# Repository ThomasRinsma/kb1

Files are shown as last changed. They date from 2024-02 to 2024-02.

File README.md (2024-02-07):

# `kb1`: a fully DIY mechanical keyboard

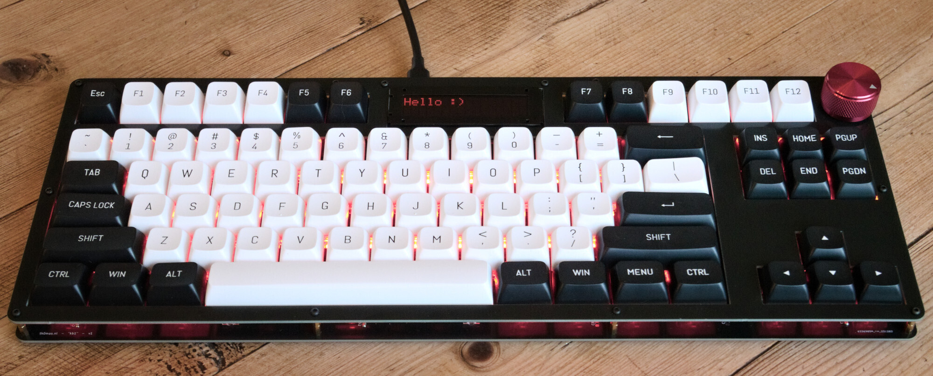
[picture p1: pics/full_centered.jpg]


Features:

- Mechanically built using two PCBs and a few screws and standoffs.
- Proper "tenkeyless" layout, compatible with Cherry MX-style switches (mine with Kailh box crystal jades)
- Per-key RGB backlight using reverse-mounted SK6812 neopixels
- Featuring an old-school 16x2 character display
- And of course a _knob_ (rotary encoder)
- Based on the Raspberry Pi Pico and [KMK](https://github.com/KMKfw/kmk_firmware)

## Why?

To challenge myself and practice PCB design!

Is it tons of fun to design and build your own keyboard from scratch? Hell yeah. Would I recommend this board for daily use? Not really :^)

## PCB

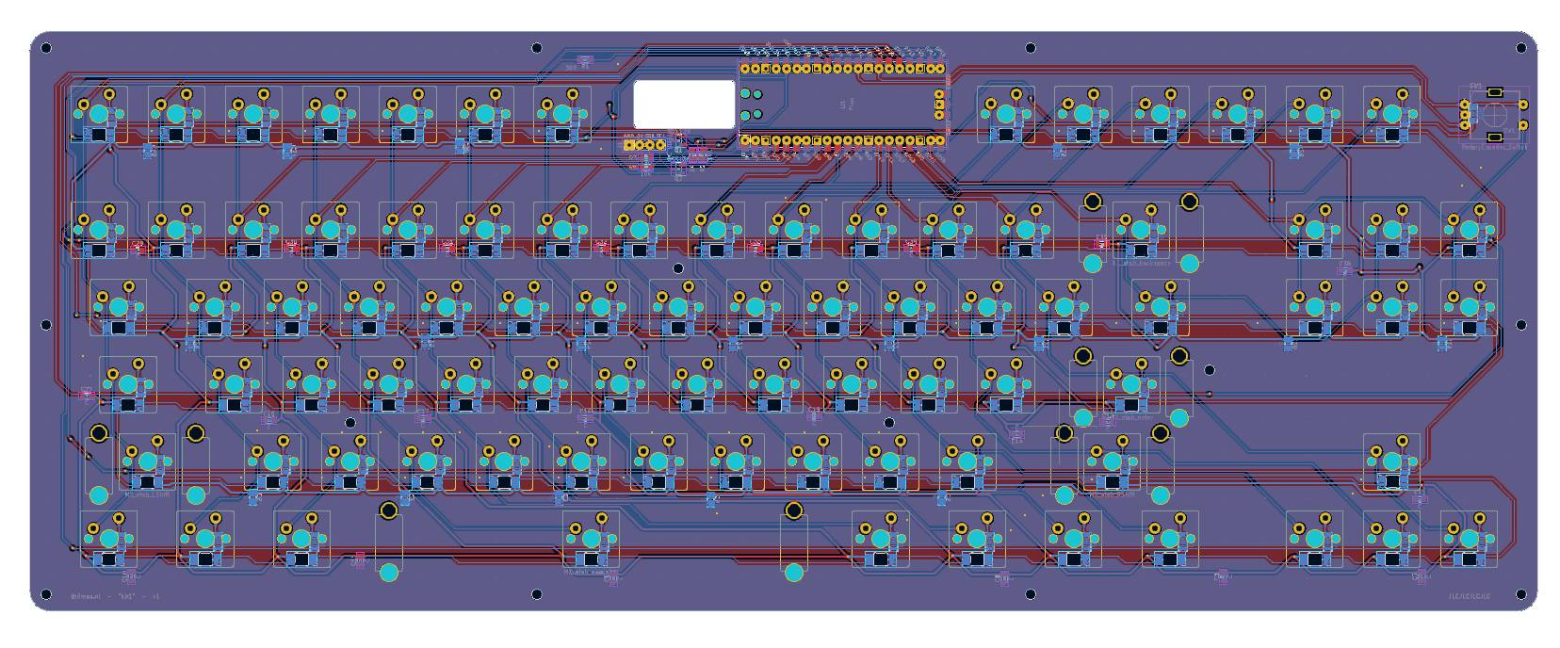
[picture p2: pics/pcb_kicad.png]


See `hardware/` for the KiCad files. There is a `gerbers/` folder with ZIP files ready to upload to a PCB fab.

## Firmware

Installing:
1. Grab Circuitpython, the Adafruit Circuitpython Neopixel library, and the KMK base files
2. Copy `firmware/*.py` to your Circuitpython drive

It's just a simple KMK setup with scaffolding code for the display and RGB. Actually doing something with the display is still TBD.

As a demo there is currently a bit of logic to map individual RGB leds to keys so it can light up a key when pressed. Twisting the knob changes the overall backlight color.

## Pics

| | |
|:---:|:---:|
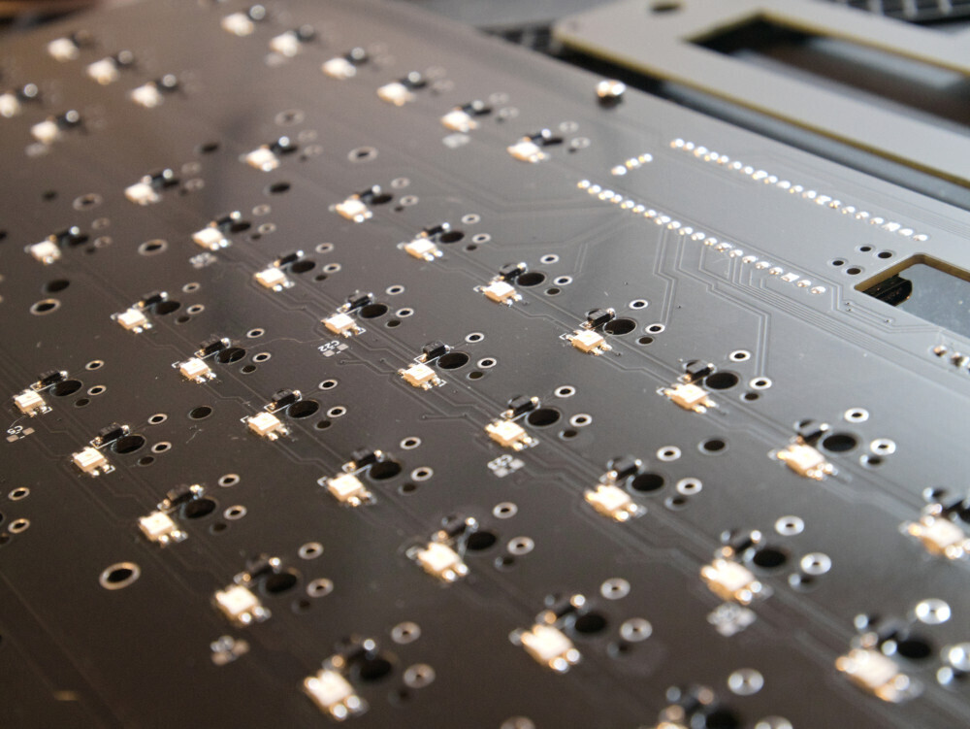
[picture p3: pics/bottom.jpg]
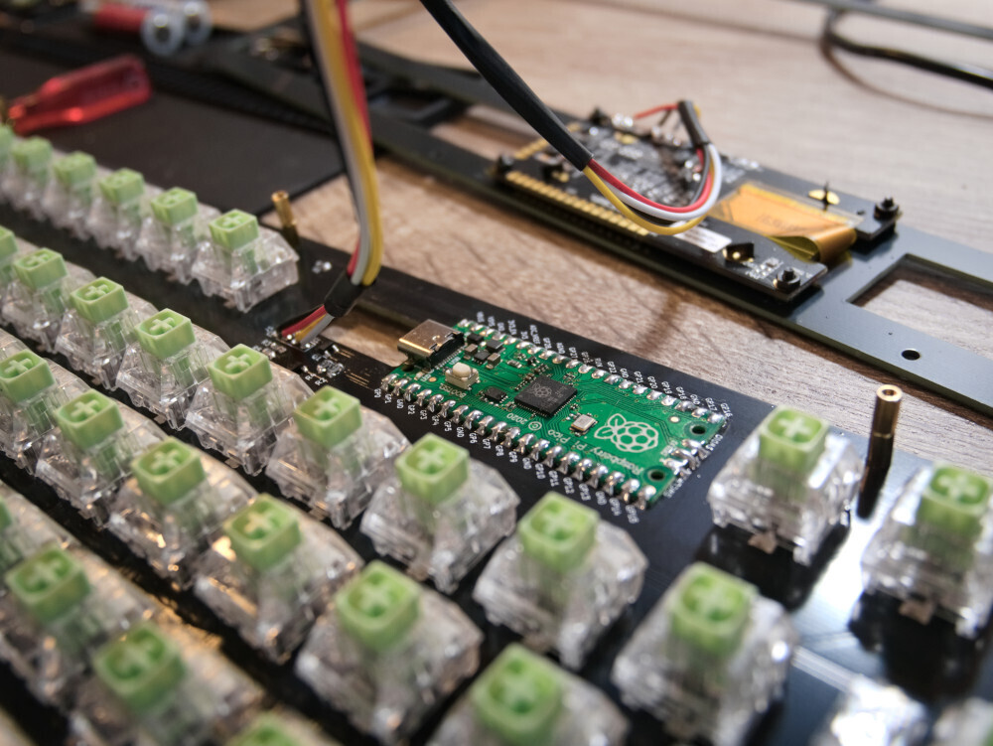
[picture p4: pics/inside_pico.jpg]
|||
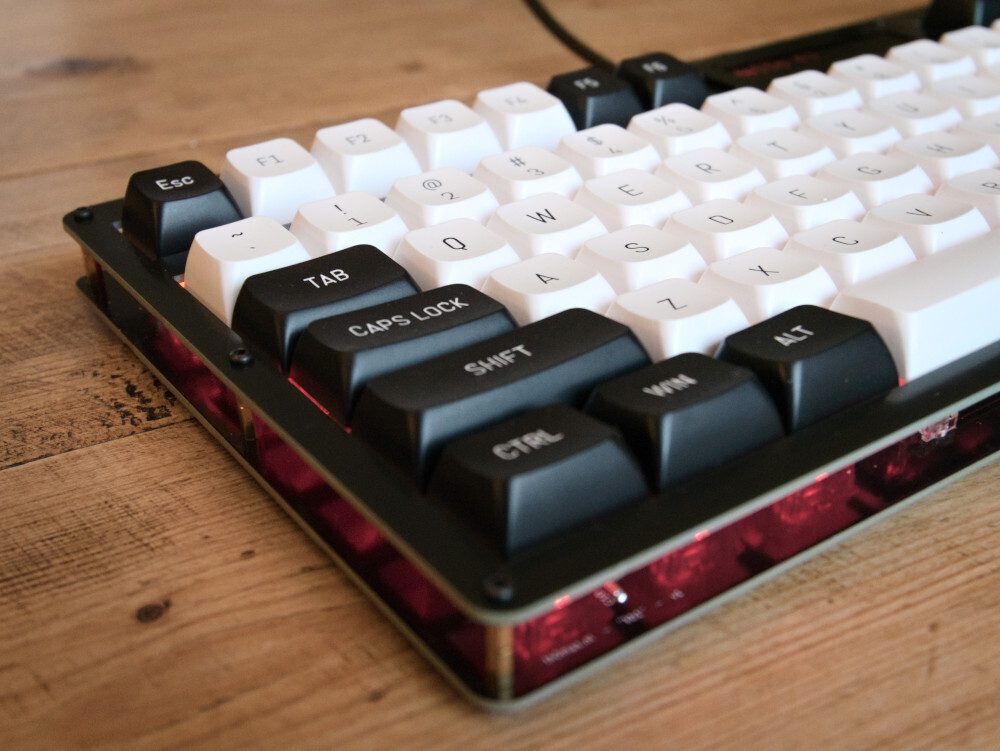
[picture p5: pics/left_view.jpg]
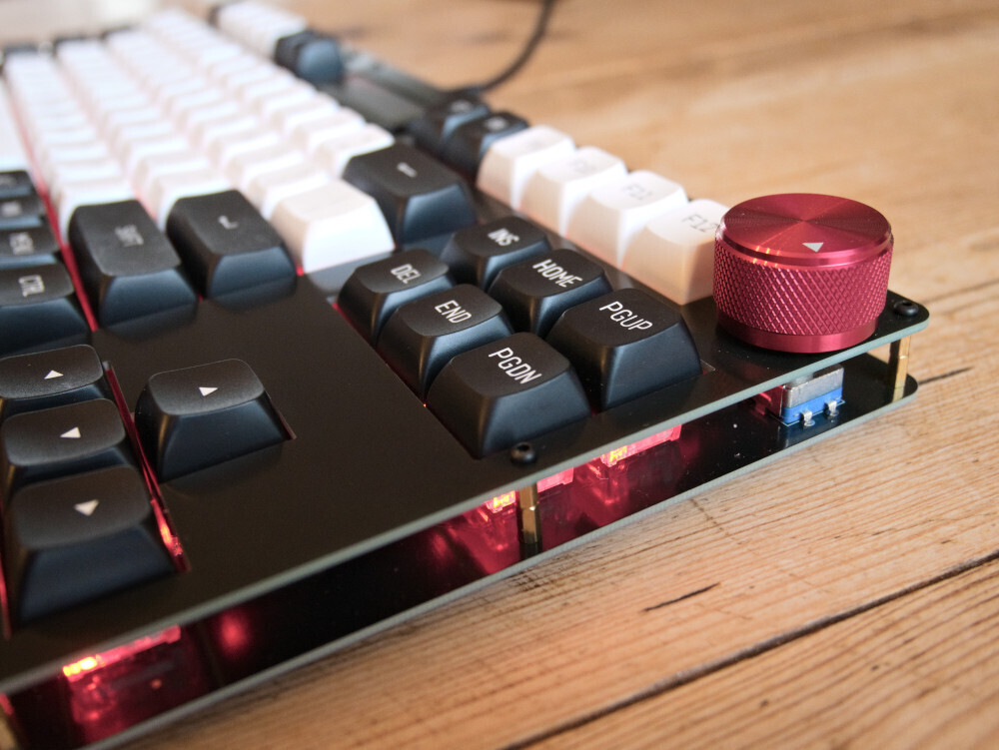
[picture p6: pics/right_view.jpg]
|||
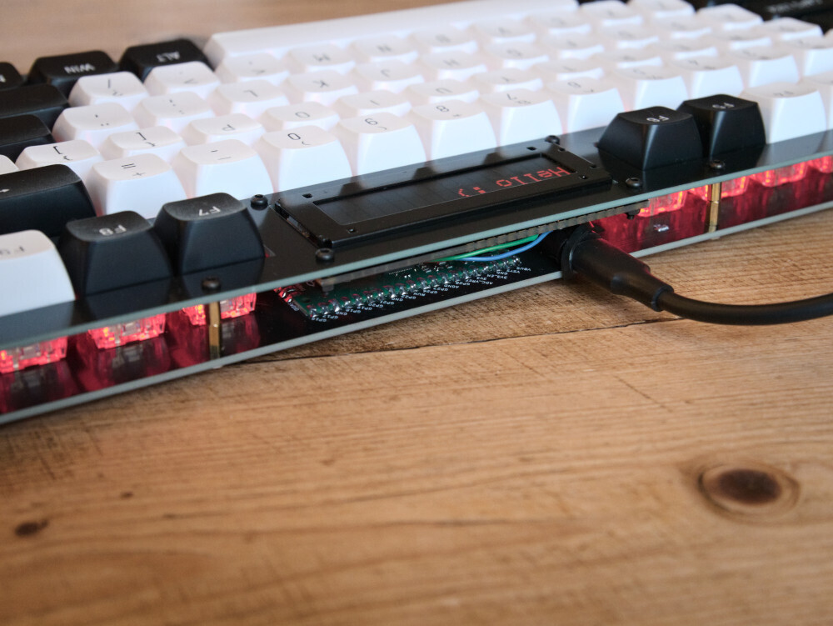
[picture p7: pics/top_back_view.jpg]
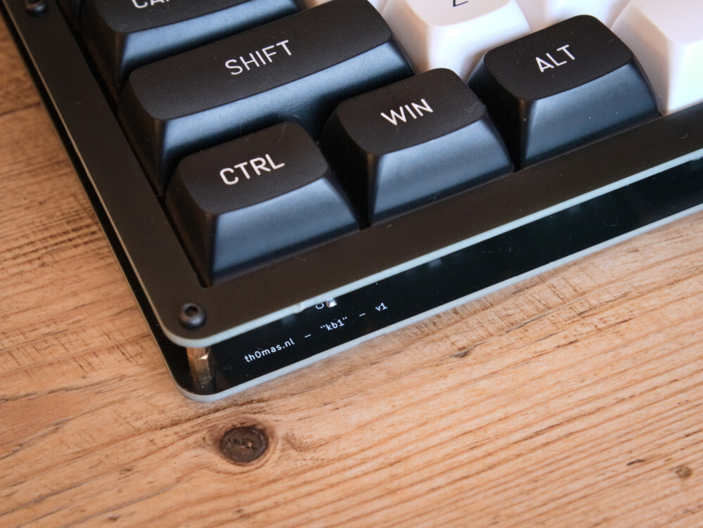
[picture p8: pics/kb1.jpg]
|||

## Errata / improvements for next version

Latest version: v1 (but the gerbers say v2, sorry..)

- Display pinout doesn't work well with a JST connector due to the orientation, requires manual soldering
- Pico orientation is awkward, I needed a USB type-C 90 degree adapter
- Several nuts nearly touch (covered) traces, doesn't appear to be a problem though
- The top plate could have some more copper for rigidity

## BoM

TODO

## Disclaimer 

This is my own hobby project and I'm a total PCB design newbie. Use the info and files provided here at your own risk.

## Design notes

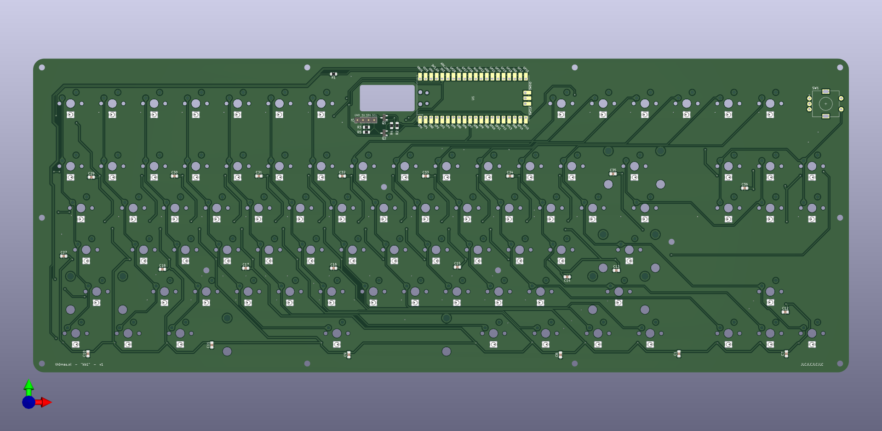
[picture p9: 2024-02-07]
pics/pcb_render.png

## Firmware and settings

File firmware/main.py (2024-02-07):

print("Starting")

import board
import neopixel
import time

from display import init, home, clear, writeData

init()
home()
writeData("Booting...")


from kmk.kmk_keyboard import KMKKeyboard
from kmk.keys import KC, make_key
from kmk.scanners import DiodeOrientation
from kmk.extensions.stringy_keymaps import StringyKeymaps
from kmk.modules.encoder import EncoderHandler


pixels = neopixel.NeoPixel(
    board.GP28,
    100,
    pixel_order=neopixel.GRB,
    brightness=1
)

COLORS = [
    (32, 0, 0),
    (32, 16, 0),
    (0, 32, 0),
    (0, 32, 32),
    (0, 0, 32),
    (16, 0, 32),
    (32, 32, 32),
    (0, 0, 0),
]

pixel_idle_color = 0

keyboard = KMKKeyboard()
keyboard.extensions.append(StringyKeymaps())

encoder_handler = EncoderHandler()
keyboard.modules.append(encoder_handler)

keyboard.col_pins = (board.GP26,board.GP27,board.GP2,board.GP3,board.GP4,board.GP5,board.GP6,board.GP7,board.GP8,board.GP9,board.GP10,board.GP11,board.GP12,board.GP13,board.GP14)
keyboard.row_pins = (board.GP15,board.GP20,board.GP19,board.GP18,board.GP17,board.GP16)
keyboard.diode_orientation = DiodeOrientation.COL2ROW
encoder_handler.pins = ((board.GP21, board.GP22, None),)  # Encoder click is handled via key matrix (top right)

def handle_encoder_click(key, kb, kc, coord):
    print(f"encoder click")

def handle_encoder_rotate(key, kb, kc, coord):
    global pixel_idle_color
    if key.direction == 1: # left
        pixel_idle_color = (pixel_idle_color - 1) % len(COLORS)
        pass
    elif key.direction == 2: # right
        pixel_idle_color = (pixel_idle_color + 1) % len(COLORS)
        pass

    pixels.fill(COLORS[pixel_idle_color])

ENCODER_CLICK = make_key(on_press=handle_encoder_click)
ENCODER_ROTATE_LEFT = make_key(on_press=handle_encoder_rotate)
ENCODER_ROTATE_LEFT.direction = 1
ENCODER_ROTATE_RIGHT = make_key(on_press=handle_encoder_rotate)
ENCODER_ROTATE_RIGHT.direction = 2

___ = 'NO'
keyboard.keymap = [[
    'ESC', 'F1', 'F2', 'F3', 'F4', 'F5', 'F6', 'F7', 'F8', 'F9', 'F10', 'F11', 'F12', ___, ENCODER_CLICK,
    'GRV', 'N1', 'N2', 'N3', 'N4', 'N5', 'N6', 'N7', 'N8', 'N9', 'N0', 'MINS', 'EQL', 'BSPC', 'INS',
    'TAB', 'Q', 'W', 'E', 'R', 'T', 'Y', 'U', 'I', 'O', 'P', 'LBRC', 'RBRC', 'BSLS', 'DEL',
    'CAPS', 'A', 'S', 'D', 'F', 'G', 'H', 'J', 'K', 'L', 'SCLN', 'QUOT', 'ENT', 'HOME', 'PGUP',
    'LSFT', 'Z', 'X', 'C', 'V', 'B', 'N', 'M', 'COMM', 'DOT', 'SLSH', 'RSFT', 'UP', 'END', 'PGDN',
    'LCTL', 'LGUI', 'LALT', 'SPC', 'RALT', 'RGUI', 'WINMENU', 'RCTL', ___, ___, 'LEFT', 'DOWN', 'RGHT',
]]

# leds go zig-zag so this needs to be manually defined
leds_order = [
    0, 1, 2, 3, 4, 5, 6, 7, 8, 9, 10, 11, 12, -1, -1, 29, 28, 27,
    26, 25, 24, 23, 22, 21, 20, 19, 18, 17, 16, 15, 30, 31, 32, 33,
    34, 35, 36, 37, 38, 39, 40, 41, 42, 43, 44, 59, 58, 57, 56, 55,
    54, 53, 52, 51, 50, 49, 48, 47, 14, 13, 60, 61, 62, 63, 64, 65,
    66, 67, 68, 69, 70, 71, 72, 45, 46, 83, 82, 81, 80, 79, 78, 77,
    76, -1, -1, 75, 74, 73]

def handle_before_press(key, kb, kc, coord):
    pixels.fill(COLORS[pixel_idle_color])
    pixels[leds_order[coord]] = (255, 0, 0)
    
    return True

def handle_after_press(key, kb, kc, coord):
    # print(f"after press: {key}")
    return True


# Attach press event handlers
for key_name in keyboard.keymap[0]:
    # Skip special keys (encoder)
    if type(key_name) != str:
        continue

    KC[key_name].before_press_handler(handle_before_press)
    KC[key_name].after_press_handler(handle_after_press)

encoder_handler.map = [
    ((ENCODER_ROTATE_RIGHT, ENCODER_ROTATE_LEFT, None),)
]

home()
clear()
writeData("Hello :)")

pixels.fill(COLORS[pixel_idle_color])

if __name__ == '__main__':    
    keyboard.go()

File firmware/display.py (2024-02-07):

import time
import board
import busio

# Kindly transcribed (stolen) from pedro11x:
# https://github.com/pedro11x/Arduino-US2066-OLED

scl = board.GP1
sda = board.GP0
i2c = busio.I2C(scl, sda)#, freq=400000)

addr = 0x3c
OLED_Command_Mode = 0x80
OLED_Data_Mode = 0x40
DEFAULT_STATE = 0x0C # OLED is ON, no cursor
ON = 0x04
BLINKING_CURSOR = 0x01

state = 0

def init():
    while not i2c.try_lock():
        pass

    # *** I2C initialization from the OLEDM1602 datasheet *** # 
    
    
    # Disable internal regulator
    # sendCommand(0x2a) # RE=1
    # sendCommand(0x71)
    # sendCommand(0x00)
    # sendCommand(0x28) # RE=0, IS=0

    # set display to OFF
    sendCommand(0x08)

    # Set display clock devide ratio, oscillator freq
    sendCommand(0x2a) # RE=1
    sendCommand(0x79) # SD=1
    sendCommand(0xd5)
    sendCommand(0x70)
    sendCommand(0x78) # SD=0

    # Set display mode
    sendCommand(0x08)

    # Set remap
    sendCommand(0x06)

    # CGROM/CGRAM Management
    sendCommand(0x72)
    sendData(0x01)    # ROM A
    
    # Set OLED Characterization
    sendCommand(0x2a) # RE=1
    sendCommand(0x79) # SD=1
    
    
    # Set SEG pins Hardware configuration
    sendCommand(0xda)
    sendCommand(0x10)

    # Set contrast control
    sendCommand(0x81)
    sendCommand(0xff)

    # Set precharge period
    sendCommand(0xd9)
    sendCommand(0xf1)

    # Set VCOMH Deselect level
    sendCommand(0xdb) 
    sendCommand(0x30)

    # Exiting Set OLED Characterization
    sendCommand(0x78) # SD=0
    sendCommand(0x28) # RE=0, IS=0

    # Clear display
    sendCommand(0x01)

    # Set DDRAM Address
    sendCommand(0x80)

    time.sleep(0.1)
    # Set display to ON
    sendCommand(0x0c)


def cursor(row, col):
    row_offsets = [0x00, 0x40];
    sendCommand(0x80 | (col + row_offsets[row]))

def clear():
    sendCommand(0x01)

def off():
    global state
    state &= ~ON;
    updateState()

def on():
    global state
    state |= ON;
    updateState()

def home():
    cursor(0,0)

#def blinkingCursor(state):
#   if state:
#       state = state | BLINKING_CURSOR
#   else
#       state = state & ~BLINKING_CURSOR
#   updateState()


def writeData(data):
    for c in data:
        sendData(ord(c))


def updateState():
    global state
    print(f"state = {state}")
    sendCommand( 0x08 | state )

def sendCommand(command):
    print(f"Sending command: {command:x}");
    res = i2c.writeto(addr, bytearray([OLED_Command_Mode, command]))
    print(res)

def sendData(data):
    res = i2c.writeto(addr, bytearray([OLED_Data_Mode, data]))
    print(res)

def sendDataContinuation(data):
    res = i2c.writeto(addr, bytearray([OLED_Data_Mode | OLED_Command_Mode, data]))
    print(res)

def contrast(cont):
    sendCommand(0x2A)
    sendCommand(0x79)      # Set OLED Command set

    sendCommand(0x81)      #  Set Contrast
    sendCommand(cont)      #  send contrast value
    sendCommand(0x78)      #  Exiting Set OLED Command set
    sendCommand(0x28)
